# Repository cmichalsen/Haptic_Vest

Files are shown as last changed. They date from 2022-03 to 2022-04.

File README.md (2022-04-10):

# Haptic Vest
Developing a Haptic Vest similar to https://www.bhaptics.com/tactsuit/tactsuit-x40. There will be 40 motors total, 20 
the front and 20 on the back. The vest will be controlled using an ESP8266 that communicates with a desktop application
over a home network via websockets. The desktop application is designed to work with games that support BHaptics using 
their available websocket interface on localhost port 15881.

This project was inspired by https://github.com/bhaptics/tact-python and https://github.com/PointlesslyUseful/VRVest. 
Thank you! More information on BHaptics interface can be found at https://github.com/bhaptics/haptic-library. I am 
initially focusing on the front vest for development simplicity. Many of the parts chosen were what I had on hand. 
I expect these to change later on.

I decided to start this project because I did not see many DIY solutions online. I also thought this would be a great 
opportunity to meet and work with others. Please feel free to join in on this. 

<div style="display: flex;justify-content: center;">
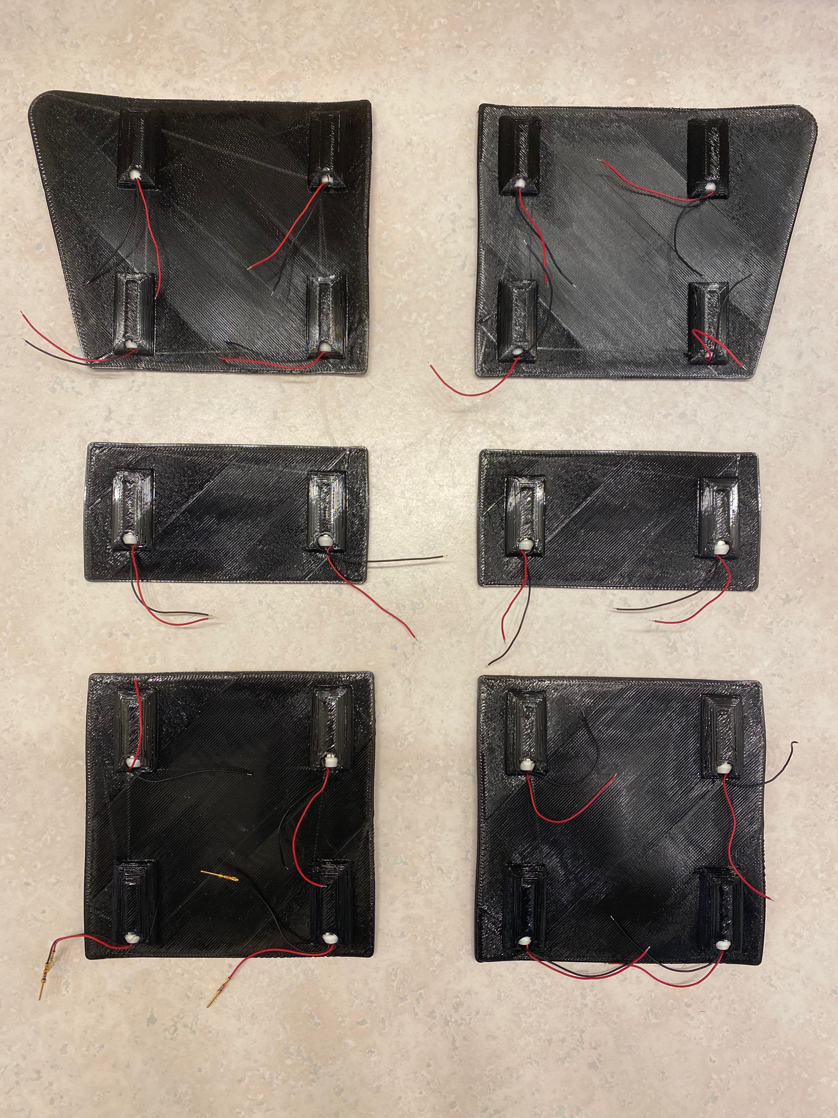
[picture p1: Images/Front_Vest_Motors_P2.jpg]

</div>

## Parts
| Part Description | Quantity | Links | Notes |
|:---:|:---:|:---:|:---:|
| ESP8266 ESP-12E | 1 | <a href="https://www.amazon.com/KeeYees-Internet-Development-Wireless-Compatible/dp/B07HF44GBT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">Amazon</a> | Microcontroller for haptic vest. Listens for inputs from Haptic game server and controls motors. |
| 2N2222 NPN Transistor | 40 | <a href="https://www.amazon.com/gp/product/B07QSJND47/ref=ppx_yo_dt_b_asin_title_o02_s00?ie=UTF8&psc=1">Amazon</a> | Used for switching motors on and off. These are necessary as the PWM drivers cannot handle current required for operating the motors. |
| PCA9685 PWM Driver | 3 | <a href="https://www.amazon.com/gp/product/B08C9R9MZ2/ref=ppx_yo_dt_b_asin_image_o01_s00?ie=UTF8&psc=1">Amazon</a> | Each PWM driver contains 16 channels for independently driving PWM outputs. |
| Portable USB Charger  | 1 | | I am using one with 10000mAh capacity that outputs 5V/2.1A. |
| Micro Vibration Motor | 40 | <a href="https://www.amazon.com/gp/product/B09DF9LXJR/ref=ppx_yo_dt_b_asin_title_o01_s00?ie=UTF8&psc=1">Amazon</a> | 7mmx25mm, 8000-24000rpm |

## Progress Updates
* Successfully processing incoming game data
* *Game_Server.py* communicates with Haptic vest microcontroller
* Added WiFi manager to simplify setup of the ESP8266 to your home network
* Now using PWM drivers to control motors. This only requires 2 GPIO pins on the ESP8266 for I2C interface.
* Added support for 40 motors (20 on front, 20 on back)
* Overhauled the Haptic Player to a class base structure.
* Both Path and Dots modes are supported
* Created flexible modular pads to house the vibration motors
 
## In-Progress
* Developing 3D printed case for the microcontroller and PWM drivers
* Attaching new motors to front vest
* Updating wiring diagram for implementation of the PWM drivers

## Resources
* <a href="https://designer.bhaptics.com/">Haptic Designer</a>
  * <a href="https://www.youtube.com/watch?v=Pyq9GHdchzc">Haptic Designer Tutorial</a>
* <a href="https://github.com/bhaptics/haptic-guide">bHaptics Guide</a>
  * *Good resource for vest operation examples*

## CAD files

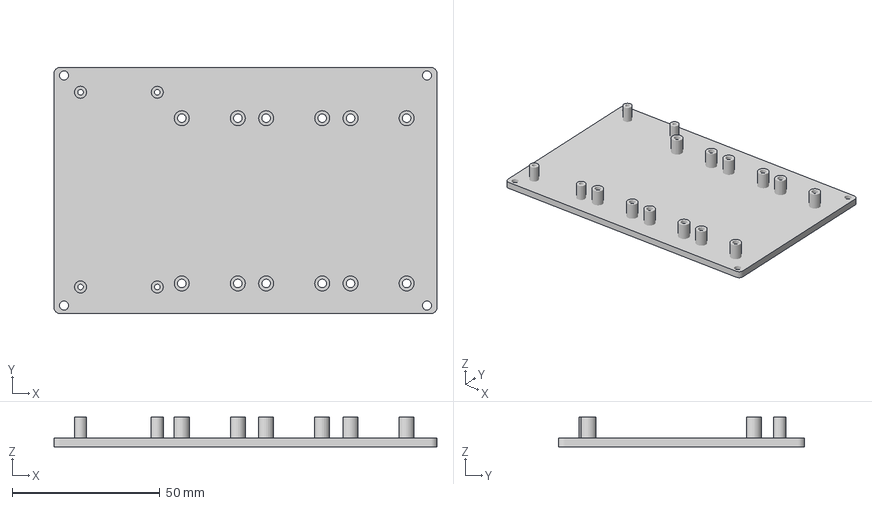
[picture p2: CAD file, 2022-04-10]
Haptic_Vest_Module/CAD/Electronics Box Base.3mf
129.8 x 83.4 x 10.0 mm

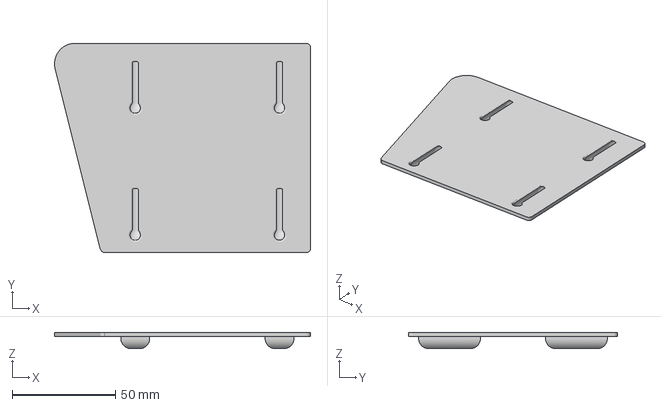
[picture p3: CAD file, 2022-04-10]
Haptic_Vest_Module/CAD/Front Upper Left Plate.3mf
124.2 x 101.6 x 8.00 mm

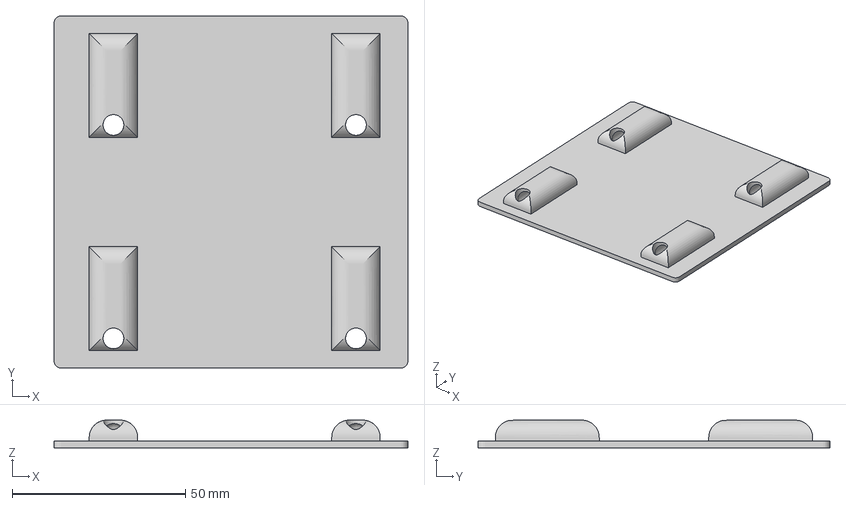
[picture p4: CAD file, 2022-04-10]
Haptic_Vest_Module/CAD/Front Lower Plates.3mf
102.1 x 101.6 x 8.00 mm

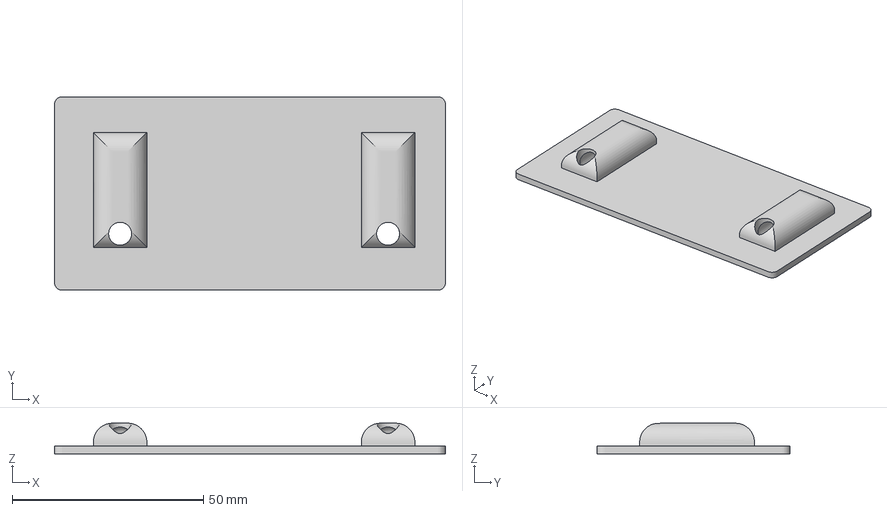
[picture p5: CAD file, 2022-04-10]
Haptic_Vest_Module/CAD/Front Middle Plates.3mf
102.1 x 50.5 x 8.00 mm

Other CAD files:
Haptic_Vest_Module/CAD/Haptic_Motor_Mount v8.f3d

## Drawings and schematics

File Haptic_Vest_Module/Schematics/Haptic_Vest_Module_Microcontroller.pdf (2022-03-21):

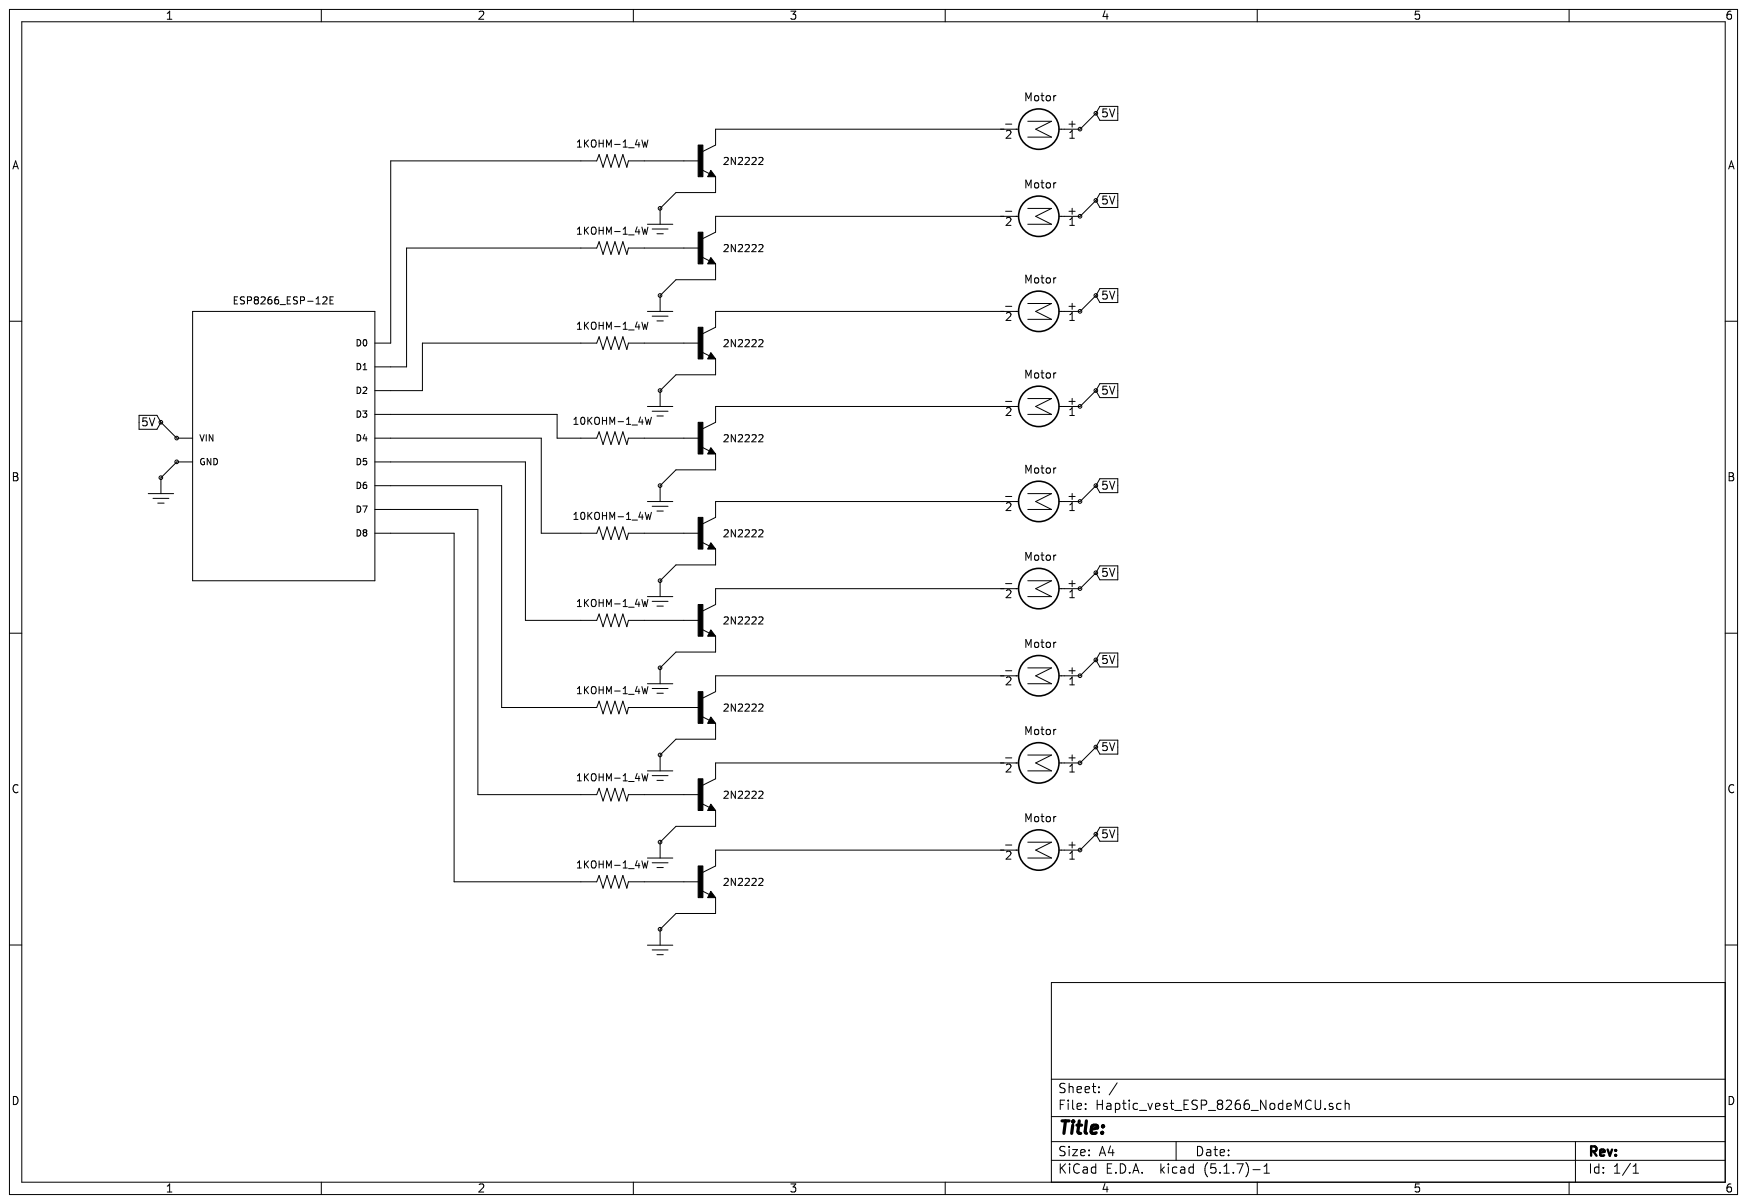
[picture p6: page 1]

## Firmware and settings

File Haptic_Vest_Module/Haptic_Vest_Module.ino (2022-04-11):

#include <FS.h> //this needs to be first, or it all crashes and burns...
#include <ESPAsyncWiFiManager.h>  // https://github.com/alanswx/ESPAsyncWiFiManager
#include <Arduino.h>
#include <ArduinoJson.h>
#include <ESPAsyncWebServer.h>
#include <string>
#include <stdio.h>
#include <stdlib.h>
#include <stdbool.h>
#include "Inputs.h"
#include "LEDs.h"
#include "EEPROM_Handler.h"
#include <Adafruit_PWMServoDriver.h> // https://github.com/adafruit/Adafruit-PWM-Servo-Driver-Library/archive/master.zip

Adafruit_PWMServoDriver pwm1 = Adafruit_PWMServoDriver(0x40); // Default (No bridges)
Adafruit_PWMServoDriver pwm2 = Adafruit_PWMServoDriver(0x41); // Bridge A0
Adafruit_PWMServoDriver pwm3 = Adafruit_PWMServoDriver(0x42); // Bridge A1


// Used for blocking other operations while connected to game server
bool GAME_SERVER_CONNECTED = false;

/****************************************************************************
     SETUP INSTRUCTIONS

     1) Get the ESP libraries using the "Prepare Arduino IDE" section at https://randomnerdtutorials.com/esp8266-nodemcu-websocket-server-arduino/
     2) Under Tools->Mangage Libraries..., search and install ArduinoJson

*****************************************************************************/

AsyncWebServer server(80);
DNSServer dns;
AsyncWebSocket ws("/ws");

/**
   Setup static IP address
*/
IPAddress ip(192, 168, 0, 53);
IPAddress gateway(192, 168, 0, 1);
IPAddress subnet(255, 255, 0, 0);

float min_pwm = 2048.0;
float max_pwm = 4095.0;
int pwm_frequency = 5000;

/**
   Set PWM Output for front vest motor

   Args:
      channel:  Target motor
      power:    Target percentage power
*/
void controlFrontMotors(uint8_t channel, float power) {
  if (channel < 16) {
    pwm1.setPWM(channel, 0, power * max_pwm);
  }
  else {
    pwm2.setPWM(channel - 16, 0, power * max_pwm);
  }
}

/**
   Set PWM Output for front vest motor

   Args:
      channel:  Target motor
      power:    Target percentage power
*/
void controlBackMotors(uint8_t channel, float power) {
  if (channel < 12) {
    // offset by 4 as front and back vest are sharing boards
    pwm2.setPWM(channel + 4, 0, power * max_pwm);
  }
  else {
    pwm3.setPWM(channel - 12, 0, power * max_pwm);
  }
}

/**
   Turn off all motors
*/
void resetAllMotors() {
  for (int i = 0; i < 20; i++) {
    pwm1.setPWM(i, 0, 0);
  }
  for (int i = 0; i < 20; i++) {
    pwm2.setPWM(i, 0, 0);
  }
  for (int i = 0; i < 20; i++) {
    pwm3.setPWM(i, 0, 0);
  }
}

/**
   Runs whenever we receive new date from the game server

   Args:
      arg:     Optional args (Not currently used)
      data:    Data from game server
      len:     Length of data from game server
*/
void handleWebSocketMessage(void *arg, uint8_t *data, size_t len)
{
  AwsFrameInfo *info = (AwsFrameInfo *)arg;

  if (info->final && info->index == 0 && info->len == len && info->opcode == WS_TEXT)
  {
    // Serial.write(data, len);
    // Ex. {"VestFront": [0.5, 0.0, 0.0, 0.0, 0.0, 0.0, 0.0, 0.0, 0.0], "VestBack": []}
//    Serial.write(data, len);
//    Serial.println("");

    // Convert incoming data to Json
    DynamicJsonDocument doc(2048);
    deserializeJson(doc, data);

    // If data contains VestFront then parse it from json
    bool vestFront = doc.containsKey("VestFront");
    if (vestFront)
    {
      JsonVariant variant = doc.as<JsonVariant>();

      int i = 0;
      // Loop through each power setting
      for (const auto &value : variant["VestFront"].as<JsonArray>())
      {
        // Command specific motor to target power level
        controlFrontMotors(i, value.as<float>());
        i++;
      }

      i = 0;
      for (const auto &value : variant["VestBack"].as<JsonArray>())
      {
        // Command specific motor to target power level
        controlBackMotors(i, value.as<float>());
        i++;
      }
    }
  }
}

/**
   Event listener that handles different asynchronous steps of the websocket protocol
*/
void onEvent(AsyncWebSocket *server, AsyncWebSocketClient *client, AwsEventType type,
             void *arg, uint8_t *data, size_t len)
{
  switch (type)
  {
    case WS_EVT_CONNECT:
      GAME_SERVER_CONNECTED = true;
      setGameServerStatus(true);
      resetAllMotors();
      Serial.println("Connected to Haptic game server");
      break;
    case WS_EVT_DISCONNECT:
      GAME_SERVER_CONNECTED = false;
      setGameServerStatus(false);
      resetAllMotors();
      Serial.println("Disconnected from Haptic game server");
      break;
    case WS_EVT_DATA:
      handleWebSocketMessage(arg, data, len);
      break;
    case WS_EVT_PONG:
      break;
    case WS_EVT_ERROR:
      resetAllMotors();
      Serial.println("WS_EVT_ERROR");
      break;
  }
}

/**
   Initialize the websocket
*/
void initWebSocket()
{
  ws.onEvent(onEvent);
  server.addHandler(&ws);
}

/**
   Initialize PWM board
*/
void initPWM() {
  pwm1.begin();
  pwm1.setPWMFreq(pwm_frequency);
  pwm2.begin();
  pwm2.setPWMFreq(pwm_frequency);
  pwm3.begin();
  pwm3.setPWMFreq(pwm_frequency);
  resetAllMotors();
}

/**
   Connect to WiFi
*/
void connectWiFi()
{
  AsyncWiFiManager wifiManager(&server, &dns);
  wifiManager.setSTAStaticIPConfig(ip, gateway, subnet);
  wifiManager.autoConnect("Haptic_Vest");
  initWebSocket();
}

/**
   Start the server
*/
void startServer()
{
  server.begin();
}

/**
   Initial Setup
*/
void setup()
{
  Serial.begin(19200);
  Serial.println("\nHaptic vest module starting...");
  initEEPROM();
  connectWiFi();
  startServer();
  initInputs();
  initPWM();
}

/**
   Main
*/
void loop()
{
  if (GAME_SERVER_CONNECTED == false)
  {
    // TODO: Work on user inputs/outputs (i.e. Status LEDs, WiFi reset button, etc.)
    //checkInputs();
  }
}

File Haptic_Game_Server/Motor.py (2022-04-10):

from Haptic_Game_Server.Constants import MOTOR_MINIMUM_POWER

# For testing with LEDs
# MOTOR_RANGE = 0.35

# For capsule motors
MOTOR_RANGE = 0.33


def migrate_motor_commands(current_commands, new_commands):
    results = []
    command_index = 0
    for command in new_commands:
        if command > current_commands[command_index]:
            results.append(command)
        else:
            results.append(current_commands[command_index])
        command_index += 1
    return results


def get_updated_dots_motor_commands(target_intensity, index):
    motor_commands = [0, 0, 0, 0, 0, 0, 0, 0, 0, 0, 0, 0, 0, 0, 0, 0, 0, 0, 0, 0]

    scaled_intensity = ((1 - MOTOR_MINIMUM_POWER) * target_intensity) + MOTOR_MINIMUM_POWER
    motor_commands[index] = scaled_intensity

    return motor_commands


def get_updated_path_motor_commands(target_x, target_y, target_intensity, motor_layouts):
    motor_commands = []

    for x, y in motor_layouts:
        scaled_intensity = ((1 - MOTOR_MINIMUM_POWER) * target_intensity) + MOTOR_MINIMUM_POWER
        motor_commands += [get_intensity_path(x, y, target_x, target_y, scaled_intensity)]

    return motor_commands


def get_intensity_path(motor_x, motor_y, target_x, target_y, target_intensity):
    """
        Calculated intensity for motor
    """
    intensity = 0

    if motor_x == target_x and motor_y == target_y:
        intensity = target_intensity
    else:
        x_dist_from_motor = abs(motor_x - target_x)
        y_dist_from_motor = abs(motor_y - target_y)

        if x_dist_from_motor >= MOTOR_RANGE or y_dist_from_motor >= MOTOR_RANGE:
            intensity = 0
        else:
            if x_dist_from_motor <= y_dist_from_motor:
                intensity = 1 - (y_dist_from_motor / MOTOR_RANGE)
            else:
                intensity = 1 - (x_dist_from_motor / MOTOR_RANGE)

    return intensity * target_intensity


def fade_in_fade_out(playback_rate):
    """
        Invert intensity rate
    """
    return playback_rate * -1

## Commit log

2022-03-21 Added README.md
    Added Schematics
    Added CAD files
    [Haptic_Motor_Mount v8.f3d, Haptic_vest_ESP_8266_NodeMCU.kicad_pcb, Haptic_vest_ESP_8266_NodeMCU.sch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]
2022-03-23 Added functions for migrating motor commands. Added some initial logic for vest commands.
2022-03-23 Fixed some logical timing errors. VestFront commands are improved but still lacking.
    [Haptics_Player.py, Motor.py]
2022-03-23 Fixed issue with single points not firing. Removed calls to test data.
    [Haptics_Player.py]
2022-03-23 Fixed errors regarding websocket messages being too large. Fixed issues where Vest is not in the data. Added some more test data.
    [Haptics_Player.py]
2022-04-01 Added thread to continuously run available tracks. Added thread to remove expired threads. Using current clock time to evaluate start/stop track times. Currently working with spam test data.
2022-04-04 Added support for Dots mode. Fixed keep alive issues with game websockets. Added more test data. Added support for "FADE_IN_FADE_OUT" playbacks.
    [Haptics_Player.py, Motor.py]
2022-04-09 Updated 3mf files
    [Front Lower Plates.3mf, Front Middle Plates.3mf, Front Upper Left Plate.3mf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]
2022-04-09 Added WiFi manager. Added PWM board interface.
2022-04-09 Updated for 20 motor array.
2022-04-10 Improved timing to use track initiation time rather than the continuously running clock. Various formatting.
2022-04-10 Now referencing current time instead of periodically updated global clock time.
2022-04-10 Fixed dots timing and issues with motor commands not resetting properly.
    [Haptics_Player.py]
2022-04-10 Improved path logic. Path should not work with more than 2 points in a single effect layer.
    [Haptics_Player.py]
2022-04-10 Switched to dynamic json for parsing incoming data at the esp8266.
2022-04-10 Added support for all front and back vest motors. Added motor resets to prevent motors from running during crash or unexpected socket interrupts.
    [Haptic_Vest_Module.ino]
2022-04-10 Fixed motor reset logic. Trying higher frequencies.
    [Haptic_Vest_Module.ino]
2022-04-10 Updated README.md with photo of latest front vest motor panels. Removed old P1 vest photo.
    [Electronics Box Base.3mf]
2022-04-11 Working with ESP32.
    Need to remove some logic outside the server callback to avoid watchdog reset issues.
    [Haptic_Vest_Module.ino]
